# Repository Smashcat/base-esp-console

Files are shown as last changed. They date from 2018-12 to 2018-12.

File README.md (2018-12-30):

# base-esp-console
The original ESP console, without USB programming circuit. Includes code for Tetris game, and nodejs game server :)

esp_tetris directory contains the multi-player Tetris game that can be built in the Arduino IDE

arduino_libs directory contains a couple of customised libraries required by Arduino IDE to build the project

gameserver.zip contains the nodejs socket server that allows multi-player. You do not need this for single player

Video of console working: https://www.youtube.com/watch?v=wQm9_M8K_SY&t=9s (older version of game)

Photo of console

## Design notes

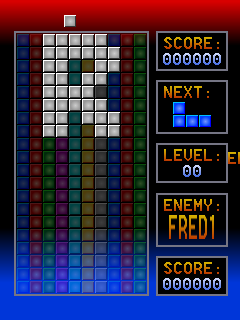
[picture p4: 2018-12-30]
esp_tetris/fw/screen.fw.png

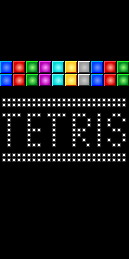
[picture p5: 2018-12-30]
esp_tetris/fw/screen-2.fw.png

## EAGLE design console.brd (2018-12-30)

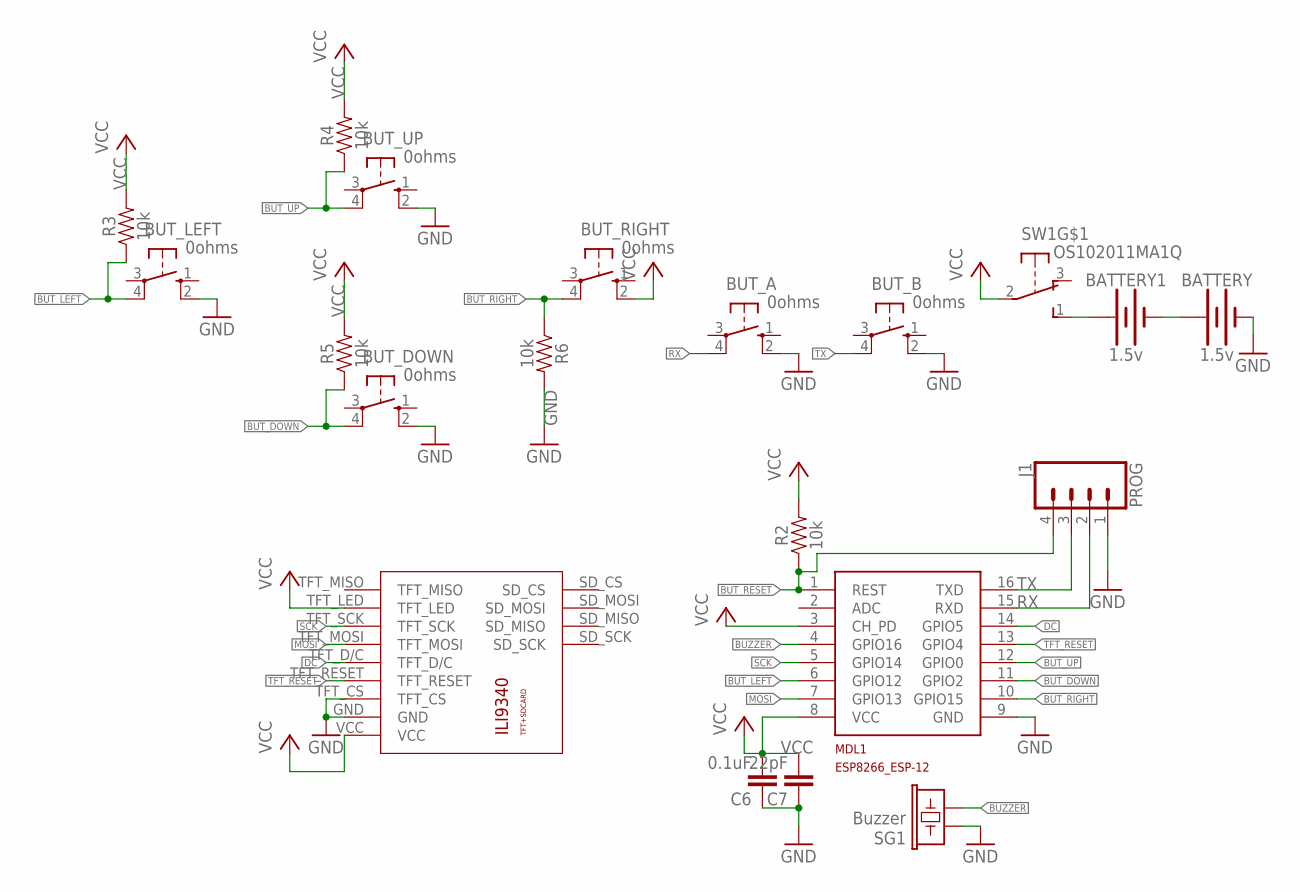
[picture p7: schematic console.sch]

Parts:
BATTERY, BATTERY1: 1.5v; BATTERY-AA
BUT_A: 0ohms; B3F-10XX
BUT_B: 0ohms; B3F-10XX
BUT_DOWN: 0ohms; B3F-10XX
BUT_LEFT: 0ohms; B3F-10XX
BUT_RIGHT: 0ohms; B3F-10XX
BUT_UP: 0ohms; B3F-10XX
C6: 0.1uF; C0603
C7: 22pF; C0603
J1: PROG; 1X04_NO_SILK
MDL1: MCU; ESP8266-ESP12
R2, R3, R4, R5, R6: 10k; 0603
SG1: Buzzer; BUZZER-CCV
SW1: OS102011MA1Q
U$1: ILI9340

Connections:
BATT+: BATTERY1.PWR@1 (+), SW1.1 (S)
BATT_LINK: BATTERY.PWR@1 (+), BATTERY1.GND@1 (-)
BUT_DOWN: BUT_DOWN.4 (P1), MDL1.11 (GPIO2), R5.1
BUT_LEFT: BUT_LEFT.4 (P1), MDL1.6 (GPIO12), R3.1
BUT_RESET: J1.4, MDL1.1 (REST), R2.1
BUT_RIGHT: BUT_RIGHT.4 (P1), MDL1.10 (GPIO15), R6.1
BUT_UP: BUT_UP.4 (P1), MDL1.12 (GPIO0), R4.1
BUZZER: MDL1.4 (GPIO16), SG1.- (2)
DC: MDL1.14 (GPIO5), U$1.TFT_D/C
GND: BATTERY.GND@1 (-), BUT_A.2 (S1), BUT_B.2 (S1), BUT_DOWN.2 (S1), BUT_LEFT.2 (S1), BUT_UP.2 (S1), C6.1, C7.1, J1.1, MDL1.9 (GND), R6.2, SG1.+ (1), U$1.GND, U$1.TFT_CS
MOSI: MDL1.7 (GPIO13), U$1.TFT_MOSI
RX: BUT_A.4 (P1), J1.2, MDL1.15 (RXD)
SCK: MDL1.5 (GPIO14), U$1.TFT_SCK
TFT_RESET: MDL1.13 (GPIO4), U$1.TFT_RESET
TX: BUT_B.4 (P1), J1.3, MDL1.16 (TXD)
VCC: BUT_RIGHT.2 (S1), C6.2, C7.2, MDL1.3 (CH_PD), MDL1.8 (VCC), R2.2, R3.2, R4.2, R5.2, SW1.2, U$1.TFT_LED, U$1.VCC

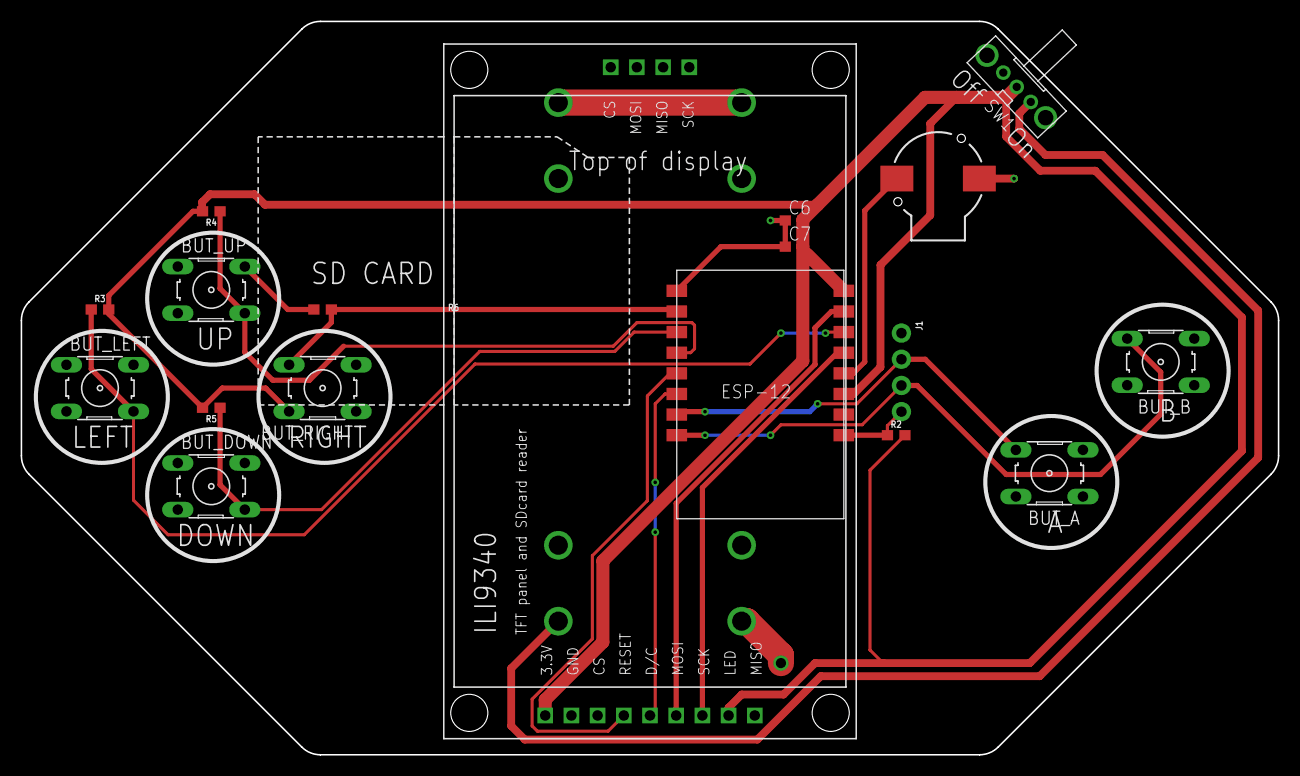
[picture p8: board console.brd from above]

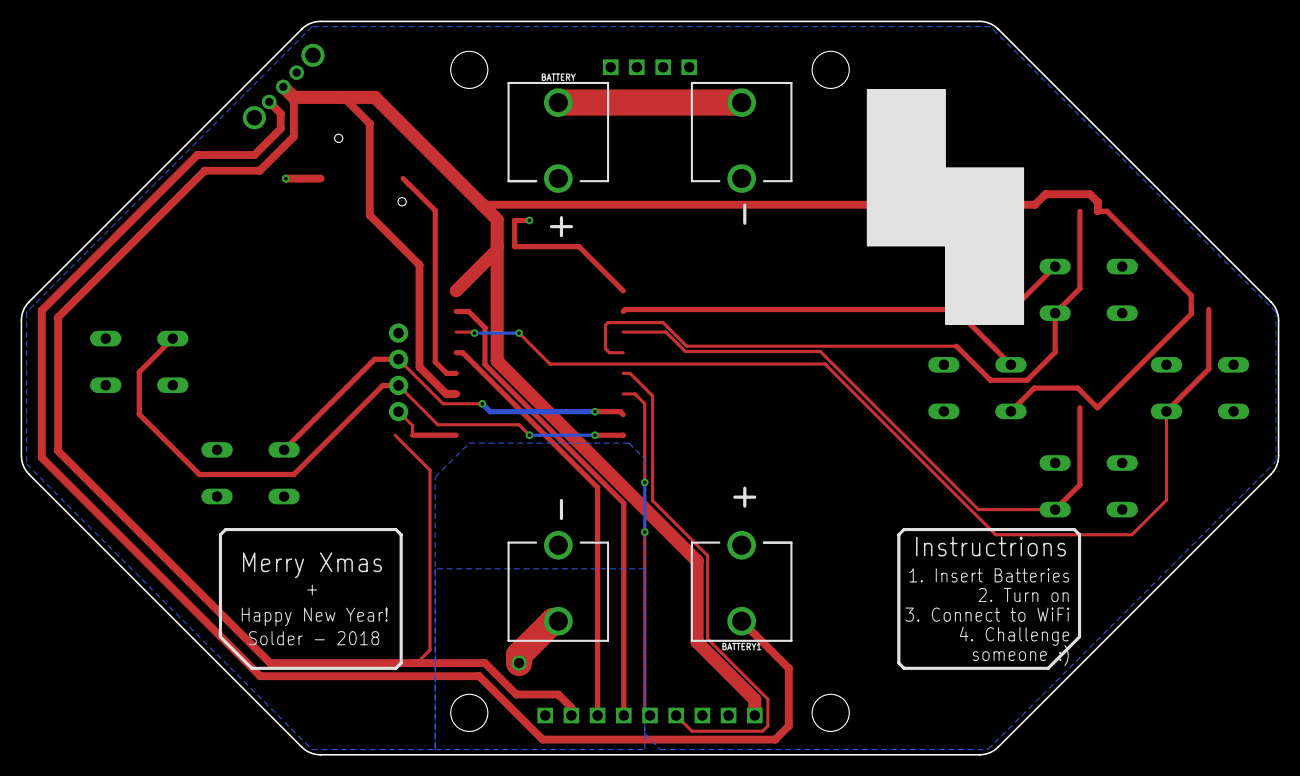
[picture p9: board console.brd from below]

Board: 2 copper layers, 121.9 x 71.1 mm, 20 parts (2 on the bottom side), 16 nets.

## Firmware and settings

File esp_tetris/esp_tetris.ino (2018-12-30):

#include "defs.h"
extern "C"
{
  #include "user_interface.h"
}

#include "pitches.h"
#include <EEPROM.h>
#if NEW_NETWORK
#include "WebSocketClient.h"
#include "ESP8266WiFi.h"

WebSocketClient webSocket(false);

#else
#include <WebSocketsClient.h>
#include <ESP8266WiFi.h>
WebSocketsClient webSocket;
#endif

#include "SPI.h"
#include "TFT_eSPI.h"
#include <Ticker.h>
#include "music.h"
#include "vars.h"
#include "gfx.h"
#include "headers.h"

TFT_eSPI tft = TFT_eSPI();
TFT_eSprite img = TFT_eSprite(&tft);
TFT_eSprite sprite1 = TFT_eSprite(&tft);
TFT_eSprite sprite2 = TFT_eSprite(&tft);
TFT_eSprite spriteTmp = TFT_eSprite(&tft);

#include "keyboard.h"
#include "menus.h"
#include "stars.h"
#if NEW_NETWORK
#include "networknew.h"
#else
#include "network.h"
#endif
#include "funcs.h"
#include "gameFuncs.h"
#include "screens.h"


void setup() {

  // Hack to allow LCD to reset and be ready before ESP is active
  pinMode(TFT_RST,OUTPUT);
  digitalWrite(TFT_RST, LOW);
  delay(25);
  digitalWrite(TFT_RST, HIGH);
  delay(100);

  setSong(0);
  za = random(256);
  zb = random(256);
  zc = random(256);
  zx = random(256);
#if USE_SERIAL
  Serial.begin(115200);
  Serial.println("\n\nOK");
#else
  pinMode(BUT_RLEFT,INPUT_PULLUP);
  pinMode(BUT_RRIGHT,INPUT_PULLUP);
#endif
  makeColors();
  tft.init();
  tft.fillScreen(0);

  system_timer_reinit();
  os_timer_setfn(&timer, timerCallback, NULL);
  os_timer_arm(&timer, 10, true); // 50FPS

  //networkStatus=NETWORK_CONNECTING; //NETWORK_OFFLINE;
  networkStatus=NETWORK_OFFLINE;
  loadConfig();
  
#if USE_SERIAL
  Serial.print("Name = ");
  Serial.println(myName);
  Serial.print("SSID = ");
  Serial.println(wifiName);
  Serial.print("Pass = ");
  Serial.println(wifiPassword);
#endif
  setState(STATE_INTRO);
//  is2Player=true;
//  setState(STATE_PLAYING);
}

void loop() {
  checkWebSocket();
  checkButtons();
  if(state!=STATE_PLAYING){
    updateStars();
  }
  // Check connection status every second
  if(connectCheckTmr>=CONNECT_CHECK_INTERVAL){
    resetConnectCheckTmr();
    checkConnection();
  }
  if(state!=STATE_PLAYING){
    showNetworkStatus();
  }
  switch(state){
    
    case STATE_INTRO:
      showIntro();
      break;
      
    case STATE_TITLE_SCREEN:
      showTitleScreen();
      break;

    case STATE_PLAYING:
      showStatePlaying();
      break;

    case STATE_CHOOSE_OPPONENT:
      chooseOpponent();
      break;

    case STATE_HIGH_SCORES:
      showHighScores();
      break;
 
    case STATE_SETTINGS:
      showSettings();
      break;

    case STATE_HELP:
      showHelp();
      break;

    case STATE_SETUP_NAME:
      showSetupName();
      break;
    
    case STATE_SETUP_WIFI:
      showSetupWiFi();
      break;

    case STATE_SETUP_ABOUT:
      showSetupAbout();
      break;

    case STATE_CHALLENGED:
      showChallenged();
      break;
      
    default:
      break;
  }
  delay(1);
  yield();
}

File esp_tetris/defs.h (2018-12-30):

// true if using the dev version of the console - button mappings are different
#define DEV_VERSION       false

// True if using dev server for networking comms (addresses below)
#define DEV_SERVER        false

// True if serial port should output debugging data. Cannot be used in conjunction with A+B buttons
#define USE_SERIAL        false

// Leave following set to false - code is not finished!
#define NEW_NETWORK       false

// Number of starts in background of out-of-game screens
#define NSTARS            512


// There should be no need to alter anything below this line!

// Ping server once a minute
#define PING_INTERVAL     6000

#define TMP_STR_LEN       500

#if DEV_SERVER
#define GAME_SERVER_URL   "192.168.0.249"
#else
#define GAME_SERVER_URL   "www.your-domain.com"
#endif

#define GAME_SERVER_PORT  9999
#define MAX_OPPONENTS     30
#define APP_SIG0          101
#define APP_SIG1          102

#define BUT_UP     0
#define BUT_RLEFT  1
#define BUT_DOWN   2
#define BUT_RRIGHT 3
#if(DEV_VERSION)
#define BUT_LEFT 4
#else
#define BUT_LEFT  12
#endif
#define TFT_RST    4
#define DC         5
#define MISO      12
#define MOSI      13
#define SCLK      14
#define BUT_RIGHT 15
#define BUZZER    16

// program states
#define STATE_INTRO         0
#define STATE_TITLE_SCREEN  1
#define STATE_HIGH_SCORES   2
#define STATE_SETTINGS      3
#define STATE_HELP          4
#define STATE_SETUP_NAME    5
#define STATE_SETUP_WIFI    6
#define STATE_SETUP_ABOUT   7

// In game
#define STATE_CHALLENGED      70
#define STATE_PICK_PLAYER     80
#define STATE_GAME_START      90
#define STATE_PLAYING         100
#define STATE_CHOOSE_OPPONENT 110
#define STATE_GAME_END        120

#define RED_TO_YELLOW   0
#define GREEN_TO_BLUE   1
#define PURPLE_TO_WHITE 2
#define WHITE_TO_BLUE   3
#define RED_TO_BLUE     4
#define BLACK_TO_RED    5
#define BLACK_TO_BLACK  6

#define KS_IDLE         0
#define KS_OPENING      1
#define KS_EDITING      2
#define KS_CLOSING      3

// Actually 7 displayed shapes, but first is blank - makes some other logic easier :)
#define TOTAL_SHAPES      8
#define TOTAL_ROTATIONS   4
#define TOTAL_COORDINATES 4

#define KEYBOARD_ACTIVE 0
#define KEYBOARD_CLOSED 1
#define KEYBOARD_SAVED  2

#define GRID_X            16
#define GRID_Y            33
#define GRID_HEIGHT       23
#define GRID_WIDTH        10
#define FIRST_VISIBLE_ROW 3

// Speed of game at start (interval in 1/20 seconds between successive downward movements of player's block)
#define GAME_SPEED_START  30
// Maximum speed of game (as above)
#define GAME_SPEED_END    1
#define REPEAT_SPEED_RESET    20;
#define REPEAT_SPEED_REPEAT   2;


#define MY_NAME_IX      3
#define MY_NAME_LEN     17

#define WIFI_SSID_IX    20
#define WIFI_SSID_LEN   65

#define WIFI_PASS_IX    85
#define WIFI_PASS_LEN   65

#define SOUND_TYPE_IX   151

#define NETWORK_OFF         0
#define NETWORK_CONNECTING  1
#define NETWORK_CONNECTED   2
#define NETWORK_OFFLINE     3
#define NETWORK_UNDEFINED   4
#define WIFI_LOGO_DISPLAY_TIME  500
// 20 = 1 second
#define CONNECT_CHECK_INTERVAL  100
#define CURSOR_BLINK_SPEED      80

#define COLOR_GREY  0x421
#define COLOR_RED   0x78
#define COLOR_GREEN 0xE003
#define COLOR_BLUE  0x0F00

#define GAMESTATE_DROPPING  0
#define GAMESTATE_DROPPED   1
#define GAMESTATE_FAST_DROP 2
#define GAMESTATE_CLEARING  3
#define GAMESTATE_GAME_OVER 4
#define GAMESTATE_WE_WIN    5
#define GAMESTATE_WE_LOSE   6

#define RESPONSE_NONE       0
#define RESPONSE_ACCEPT     1
#define RESPONSE_REJECT     2
#define RESPONSE_BUSY       3

#define SOUND_NONE          0
#define SOUND_EFFECTS       1
#define SOUND_ALL           2

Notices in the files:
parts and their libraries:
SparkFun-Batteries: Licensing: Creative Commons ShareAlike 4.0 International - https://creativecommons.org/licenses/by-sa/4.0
